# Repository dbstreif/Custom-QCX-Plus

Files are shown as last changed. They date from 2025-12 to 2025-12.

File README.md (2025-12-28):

# Custom-QCX-Plus
QRP Labs QCX+ 5W CW Radio Transceiver modified for 15m band (21MHz) frequency range. This project includes Custom Frontplate/Backplate parametric part designs, and specs/calculations for inductance and capacitance values for the transformer and low pass filter.

## Motivation
When I first began building this kit from QRP Labs, I was only a Technician Class Operator. This meant that if I wanted to get on the air and communicate globally via ionospheric propagation, I had to choose a high frequency (HF) band that I could legally transmit on. I also was restricted to only Morse Code operation on said bands, which meant that the QCX+ was the lowest barrier of entry to the world of HF and long-range communication. Now as a General Class Operator, I have more operating privileges; yet I find myself fascinated with the most pure form of radio communication, the continuous wave.

My operating band options at the time came down to 40m and 15m. The reason being, firstly, I would most likely use an end fed half wave antenna for my usual portable operation, and anything greater than a 20m antenna is quite long for all intents and purposes; and secondly, I was restricted to operating on certain bands and in-band frequency ranges. I decided that the 15m band would be best fit for me as it would give me a real design constraint, and challenge me to learn electrical principles. Also, a 15m half wave is only 7.5m, which is a small enough antenna to be portable and easily deployable.

## QCX+ Limitations
160m is not possible on the QCX+ due to crystal characteristics and 10m would introduce significant phase tuning challenges as the imaging algorithm used to display phase tuning metrics would be quite finnicky near the edges of the local oscillator range. The QCX family uses an Si5351A clock generator to create the required quadrature local oscillator (LO) signals for its direct-conversion receiver. The Si5351A can only produce two outputs with a 90deg quadrature phase difference down to about 3.2MHz. This sets the lower frequency limit for the QCX design to operate in the 80m band. The other challenge with operating at the LO edges is the phase noise introduced. When the output frequency is far from the VCO center, high divider ratios are used. At the edges, CW notes may sound unclean or raspy, weak signals might smear together, and it wouldn't be a great experience.

Here is the [datasheet](https://cdn-shop.adafruit.com/datasheets/Si5351.pdf) for the Si5351A.

## Repository Items
This repository contains a variety of different projects and calculations related to this project. Firstly, it contains inductance and capacitance values needed for proper harmonic rejection during the low pass filter stage. Secondly, it describes my thought processes and reflections of this journey, including reasoning about the [seven element Chebyshev Pi LC Low Pass Filter](https://en.wikipedia.org/wiki/Chebyshev_filter). Lastly, it includes my FreeCad parametric part designs for the Frontplate and Backplate of the custom case I built. As for the body and top, I give credit to oe7mbt for designing these. Though, because they were not designed parametrically (at least I think based on some inaccuracies), I faced problems with screw-hole alignment. You can find his creation [here](https://www.printables.com/model/65299-qrp-labs-qcx-plus-housing/files).

## Frontplate and Backplate
Here are some images of my part designs. The corner holes have countersinks so that M2.5 countersunk screws could sit flush against the plates. These plates were printed in PLA by my brother's Creality Ender-3 S1 Plus. We had just set up [Moonraker](https://moonraker.readthedocs.io/en/latest/) and [Klipper](https://github.com/Klipper3d/klipper) before printing this project, which made monitoring and adjusting print parameters really convenient.

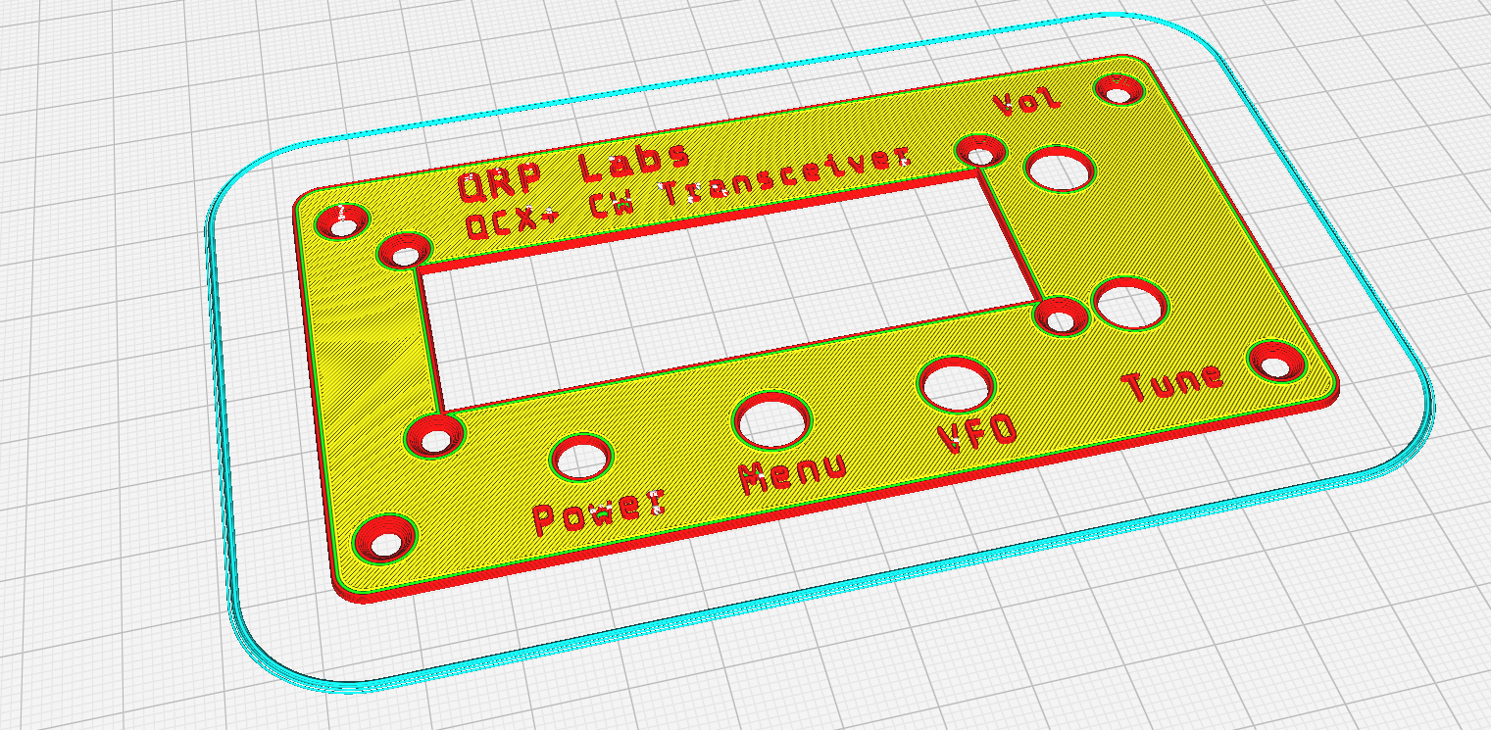
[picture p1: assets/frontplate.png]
frontplate STL Slice Frontplate Preview

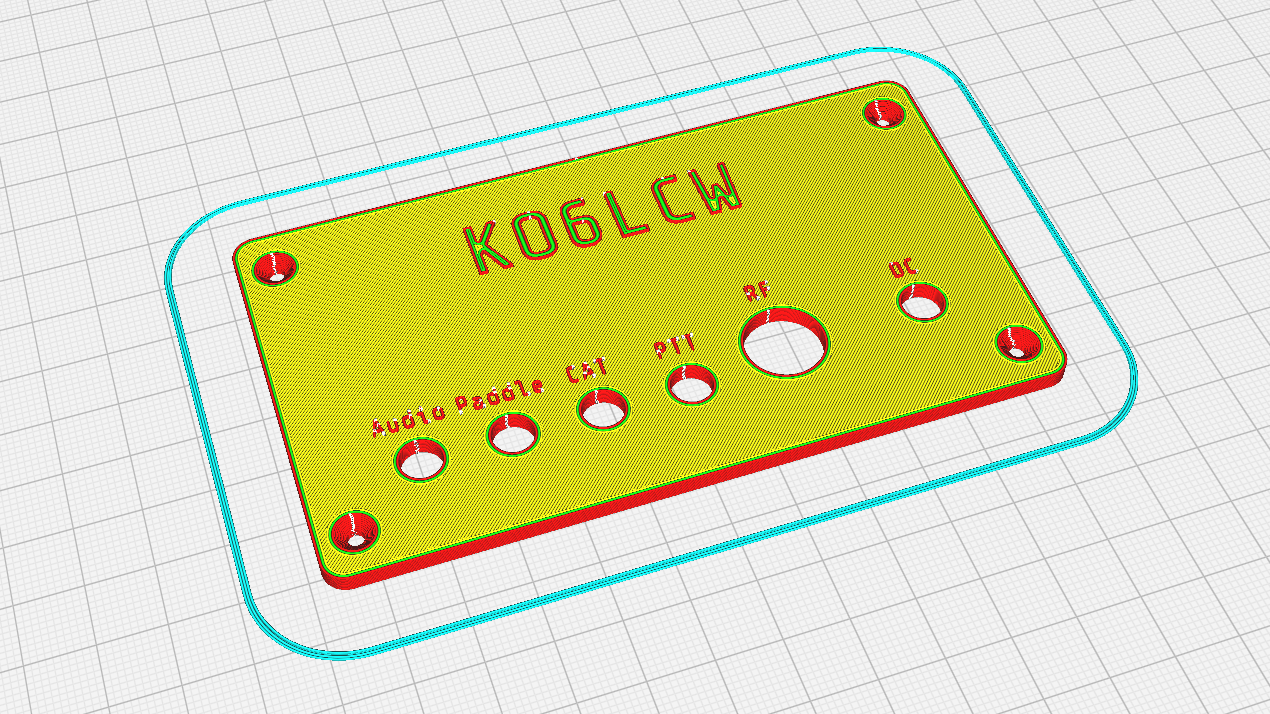
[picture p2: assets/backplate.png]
backplate STL Slice Backplate Preview

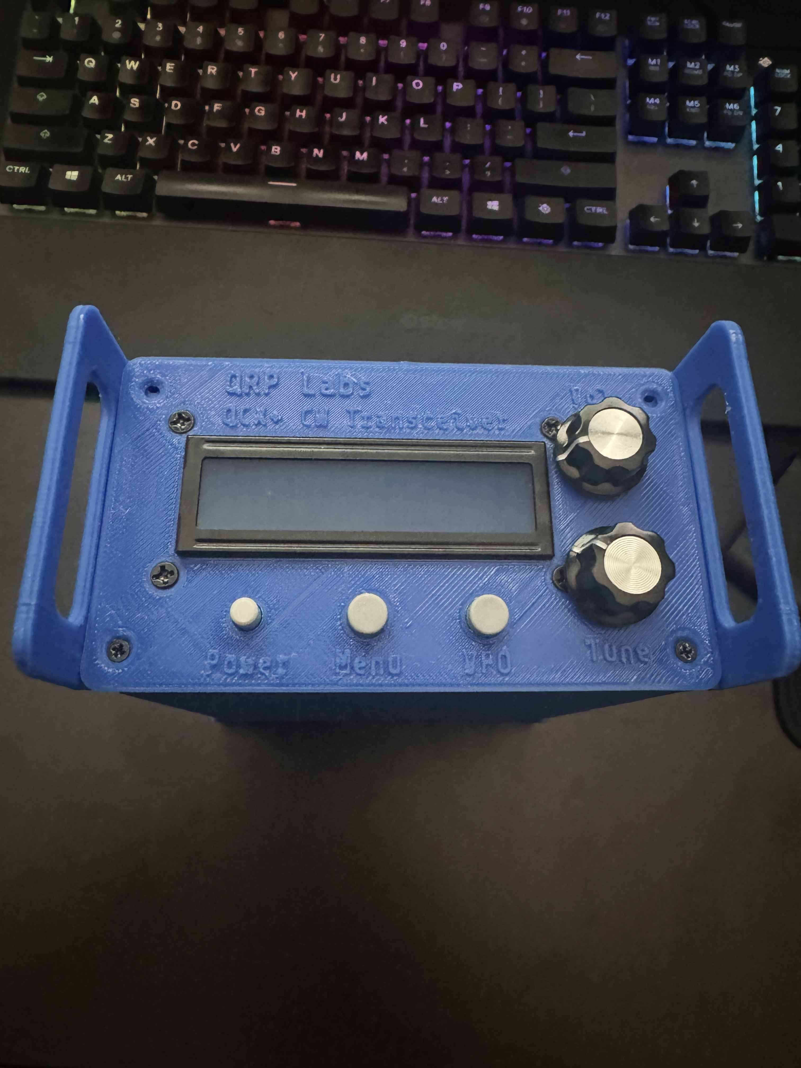
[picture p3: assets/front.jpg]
front QCX+ Front Preview

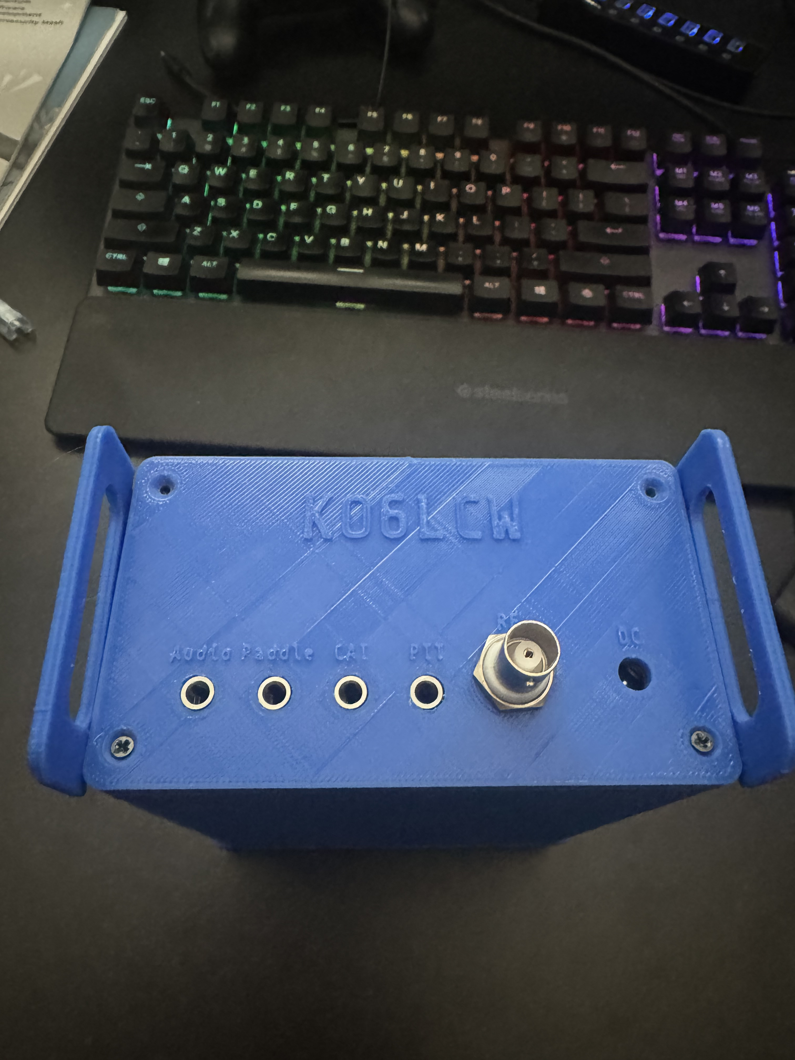
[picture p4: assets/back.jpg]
back QCX+ Back Preview

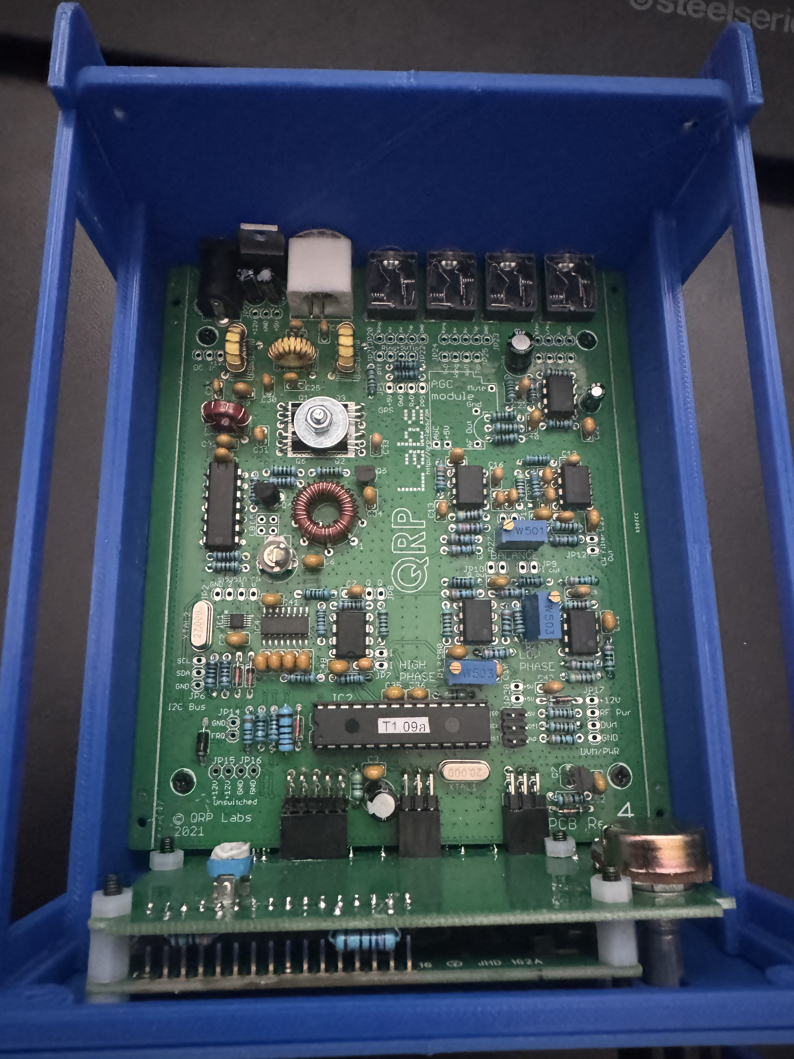
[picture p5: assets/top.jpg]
top QCX+ Top Preview

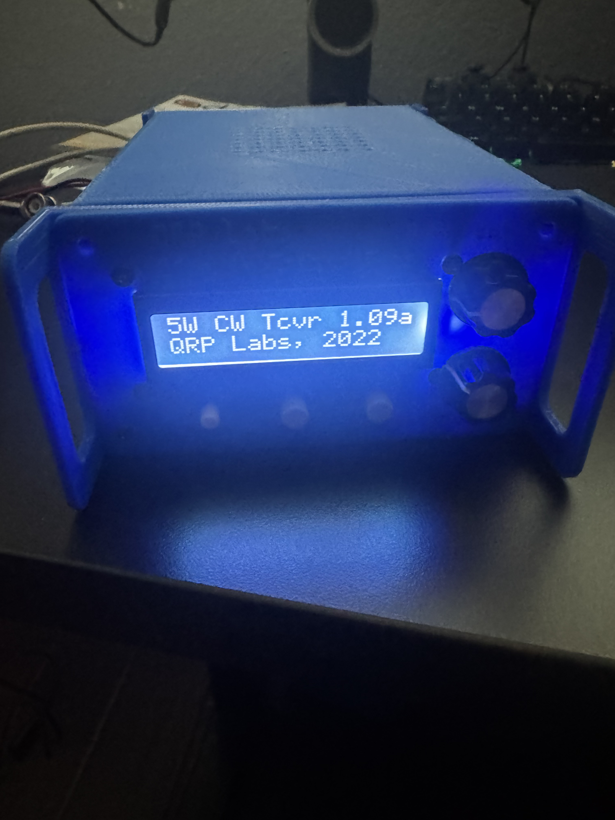
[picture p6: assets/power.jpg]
power QCX+ Powered On Preview


## Low Pass Filter Behavior
Tuning the LPF is crucial in order to maximize peak power envelope power (PEP) on transmission. On the first transmit test, the QCX+ was barely outputting 1.02W of power. After playing around with the characteristic inductance and impedance the toroidal inductors, I was able to increase output power to 3.24W with a 12V power supply. A significant increase, and close to optimal. Now the QCX+ is advertised to output around 5W PEP, however with a 12V power supply around 4W is considered maximal. If I decide to switch to a 13.8V power supply at some point, I could easily squeeze out an extra 2W. Though, I want to keep heat dissipation of the final stage power transistor low as my case is made of low polymer plastic after all.

The PEP was calculated using the Root Mean Square Voltage (RMS) PEP variant Formula: $P_{\mathrm{PEP}} = \frac{V_{\mathrm{RMS,\,peak}}^{2}}{R}$

Han's Summers uses the Omega system shortcut (8R) as we measure $V_{PP}$ using an oscope: $P_{\mathrm{PEP}} = \frac{V_{\mathrm{pp}}^{2}}{400}$

I wanted to share something interesting that I found interesting. When trying to increase inductance on L2 by "bunching up" the coil on the toroid significantly, I found that I had accidentally introduced stray capacitance and other noise. Even though output power increased to around 4.1W, the LPF was unable to correctly reject harmonic frequencies. We can observe a "double" sine wave on the oscope. 

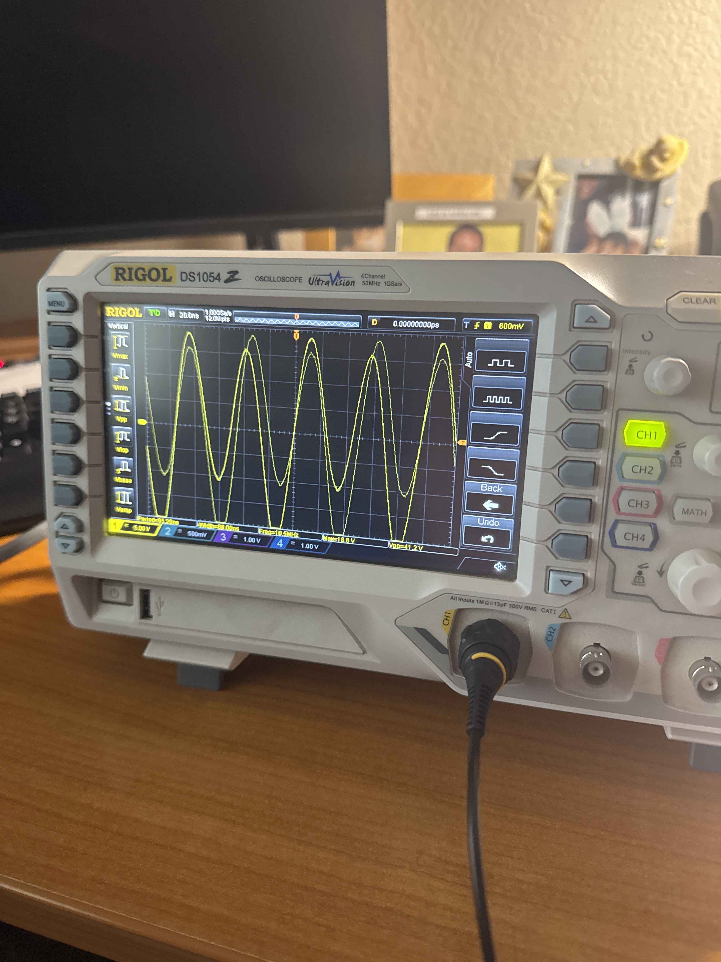
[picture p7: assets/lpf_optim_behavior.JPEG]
oscope LPF Optimization Interesting Behavior


By spacing the coil turns again, I was able to restore one clean frequency transmission or sine wave if you will. Though final tuned output power was 3.24W. I'm sure that if I were to add some turns on L2, I would have been able to squeeze more output power, however I thought that it was too much of a hassle to rewind the inductor and felt satisfied with my results.

## Conclusion
I learned a lot from this project. I have been so excited by it, that I am considering pursuing a Master's in Electrical Engineering. I find the world of RF absolutely magical and have grown a lot through this experience.

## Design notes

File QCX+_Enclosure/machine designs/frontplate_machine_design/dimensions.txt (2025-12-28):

Plate x1:
Plate: x: 116mm, y: 66mm

Radial Chamfer x4:
Radial Chamfer to Edge: r: 3.83mm

Standoff x4:
Standoff countersink outer from origin to edges: x: 3.00mm, y: 4.24mm, d: 6.00mm
Standoff hole inner from outer: d: 2.52mm, edge_dist: 1.74mm

LED Standoff x4:
Standoff countersink outer from origin to edges: x: 13.00mm, y: 20.5mm, d: 6.00mm
Standoff hole inner from outer: d: 2.52mm, edge_dist: 1.74mm

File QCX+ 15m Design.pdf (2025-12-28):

## QCX+ 15m

After receiving QRP Lab's QCX+ 5w for the 40m band, I decided that I want to operate on the 15m band instead. This is for two main reasons.

1. Antenna Length: Assuming 40m wavelength, a dipole antenna would have to be huge! 20m long or λ/2. On 15m, the typical length for each wire with 13cm tail is: 3.58m. In total it would be around 7.16m, much shorter. QE1OPW reports that at 6m height the dipole antenna performed quite well.
2. 15m band is suitable for DX no matter what time of the day, however is most useful for intercontinental communication during daylight hours, especially in years close to the solar maxima. It seems that 15m in my grid has been operating quite well in night hours. 15m band frequencies are propagated by the F2 layers of the Ionosphere.

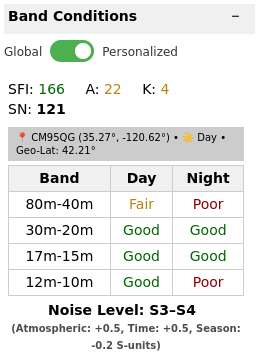
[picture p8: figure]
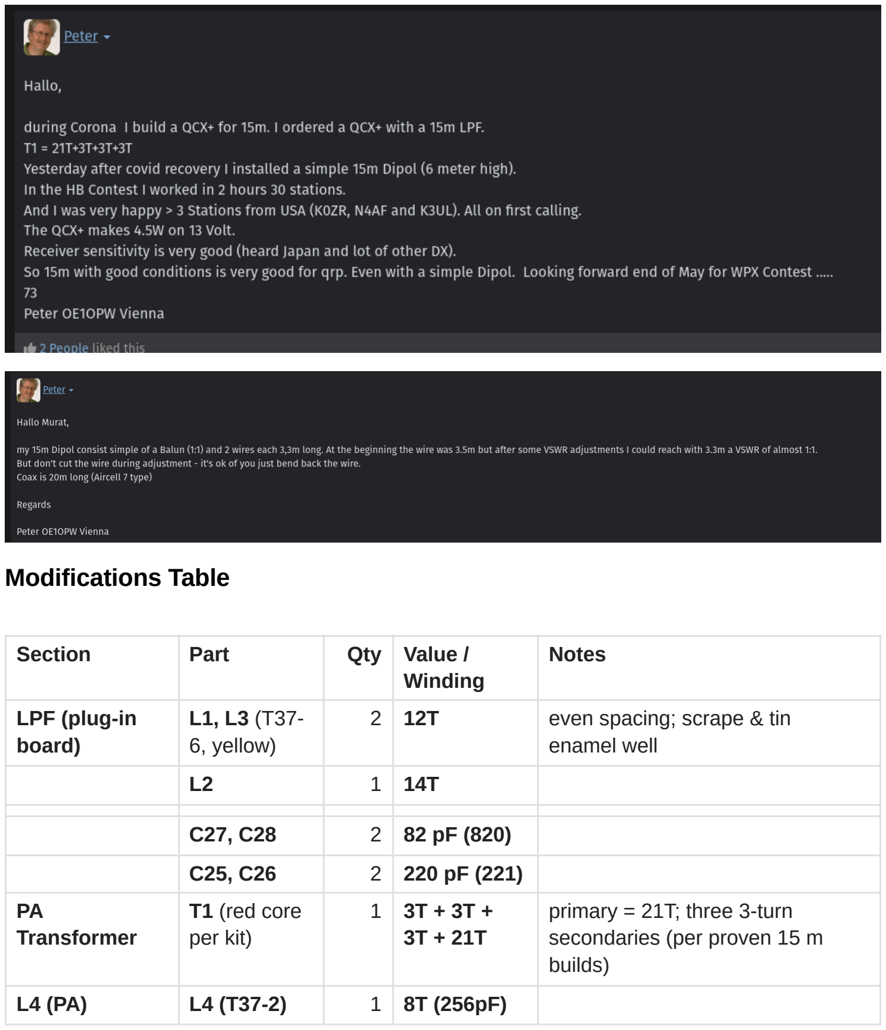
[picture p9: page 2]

### Modifications Table

Section | Part | Qty | Value / Winding | Notes
LPF (plug-in board) | L1, L3 (T37-6, yellow) | 2 | 12T | even spacing; scrape & tin enamel well
| L2 | 1 | 14T
| C27, C28 | 2 | 82 pF (820)
| C25, C26 | 2 | 220 pF (221)
PA Transformer | T1 (red core per kit) | 1 | 3T + 3T + 3T + 21T | primary = 21T; three 3-turn secondaries (per proven 15 m builds)
L4 (PA) | L4 (T37-2) | 1 | 8T (256pF)

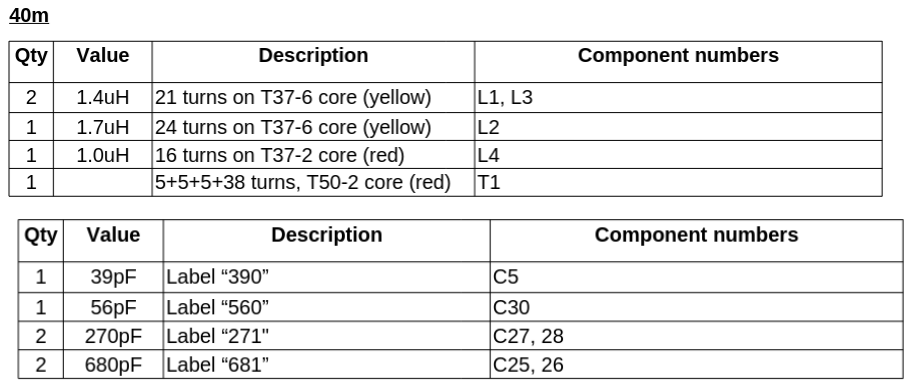
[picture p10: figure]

### Inductance Calculation for 15m LPF

QCX LPF follows a standard 7th-order Chebyshev pi-section. Each band rescales inductance and capacitance so that the cutoff frequency stays a little bit above the band's highest signal frequency:

First Let's try with 1-pole/element:

fc ∝ 1
√LC
Where,
L: Inductance
C: Capacitance

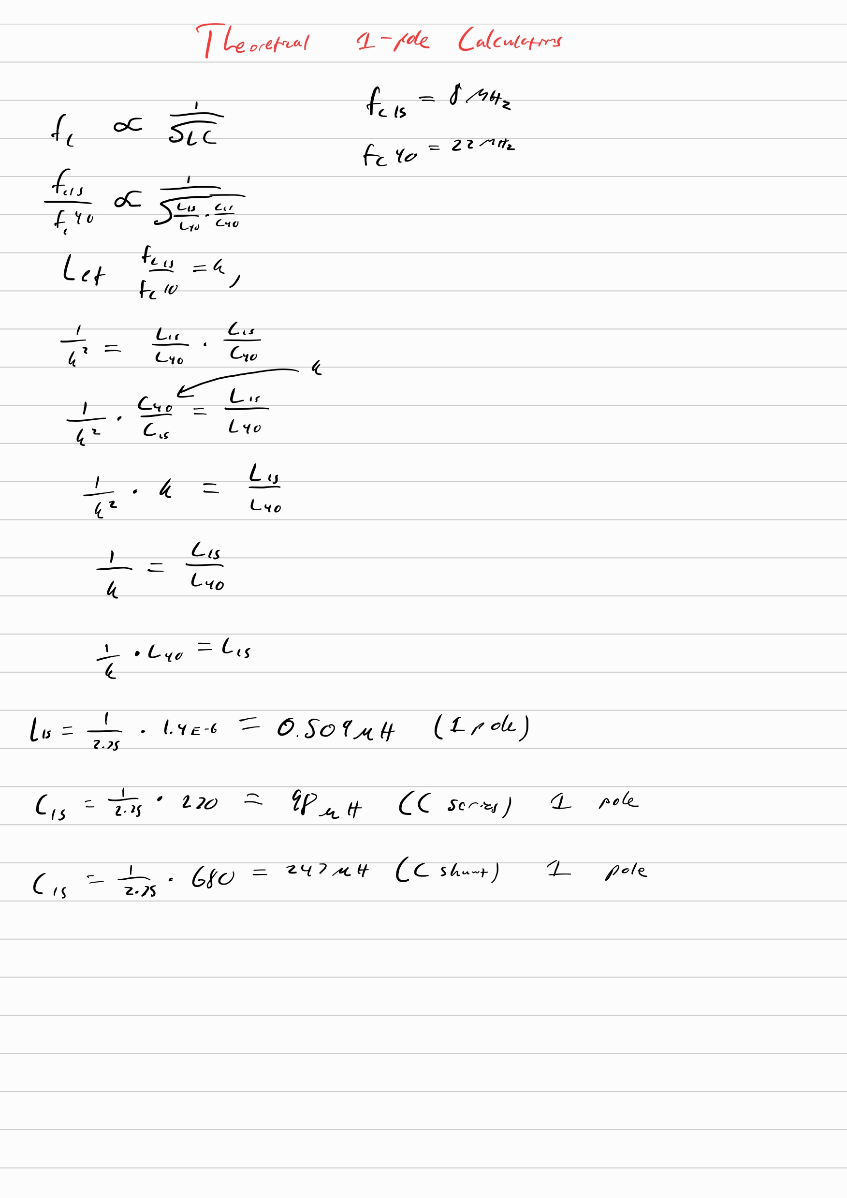
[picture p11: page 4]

Note: Capacitance was mislabeled (unit-wise) in henry. Should be micro-Farad

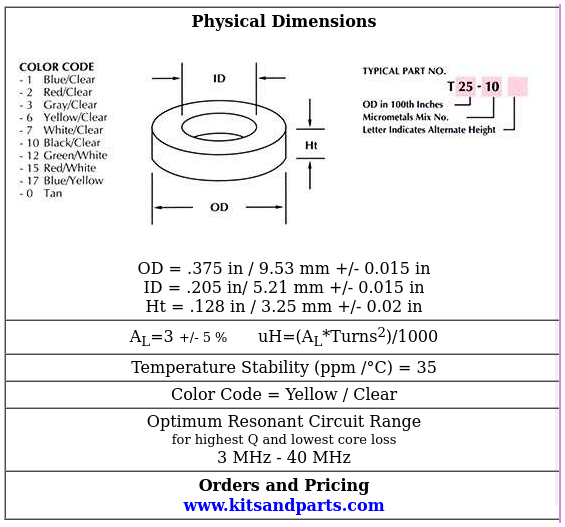
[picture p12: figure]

### W3NQN LPF Design and Values

https://qrp-labs.com/images/lpfkit/instructions2.pdf

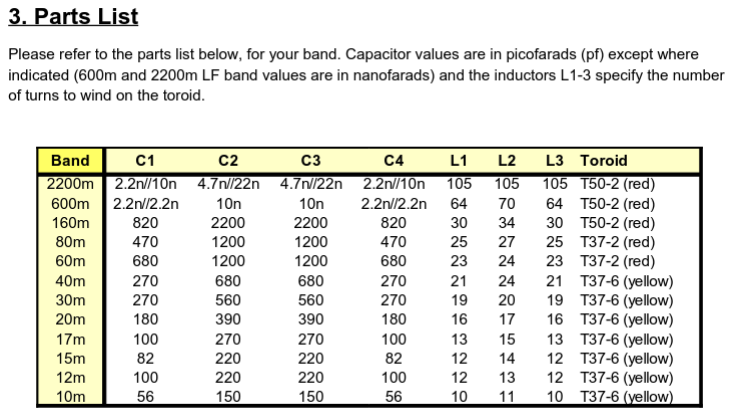
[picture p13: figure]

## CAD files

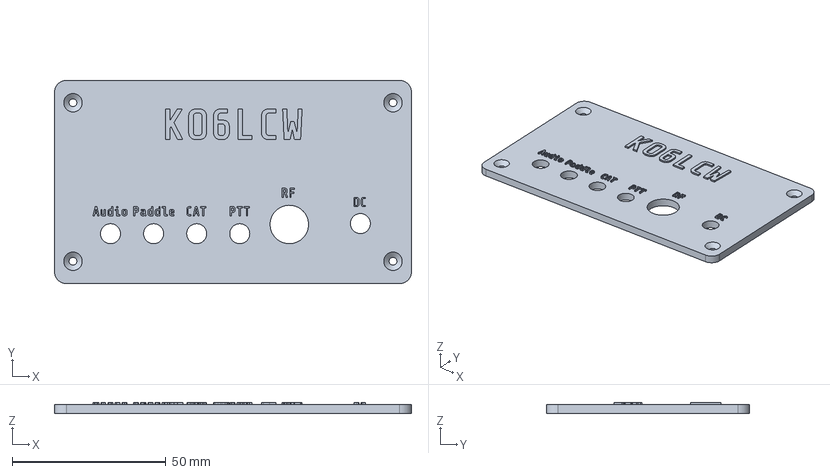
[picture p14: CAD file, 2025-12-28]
QCX+_Enclosure/machine designs/backplate_machine_design/backplate.FCStd
116.0 x 66.0 x 3.60 mm

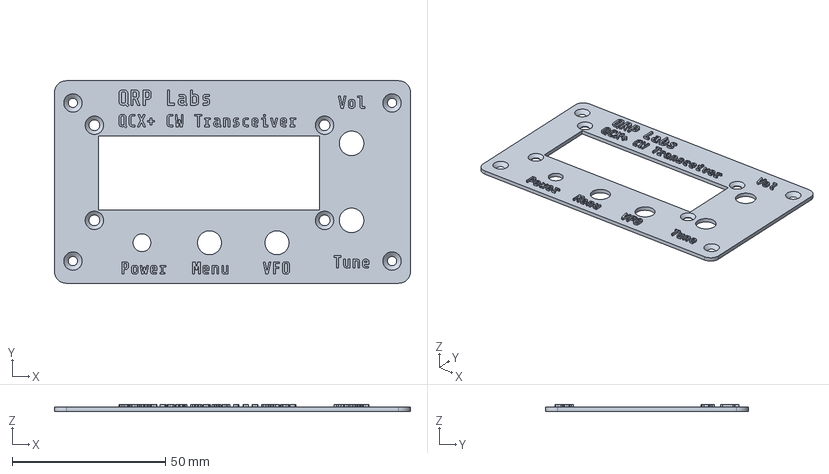
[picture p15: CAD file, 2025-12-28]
QCX+_Enclosure/machine designs/frontplate_machine_design/frontplate.FCStd
116.0 x 66.0 x 2.30 mm

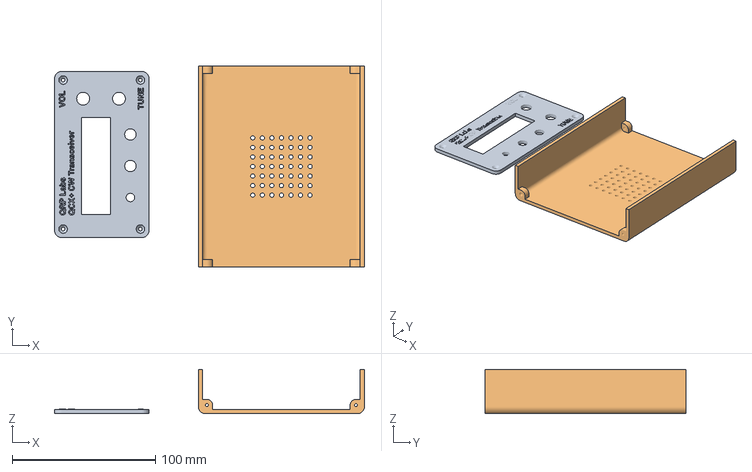
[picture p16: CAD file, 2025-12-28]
QCX+_Enclosure/QCX+ Printing Design/Printer Files/CE3S1P_QCX+-QCX+ Housing_Front&speaker.3mf
216.4 x 140.0 x 31.0 mm
QCX+-QCX+ Housing_Front.stl
QCX+-QCX+ Top_Speaker.stl

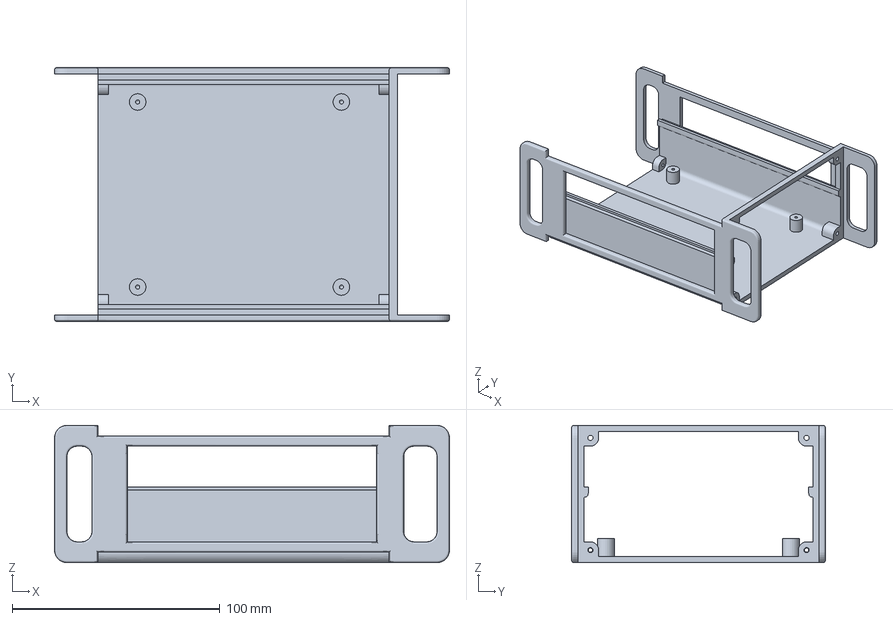
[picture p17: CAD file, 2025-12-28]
QCX+_Enclosure/QCX+ Printing Design/Printer Files/CE3S1P_QCX+-QCX+ Housing_Base_w_Protector.3mf
190.0 x 122.0 x 66.0 mm

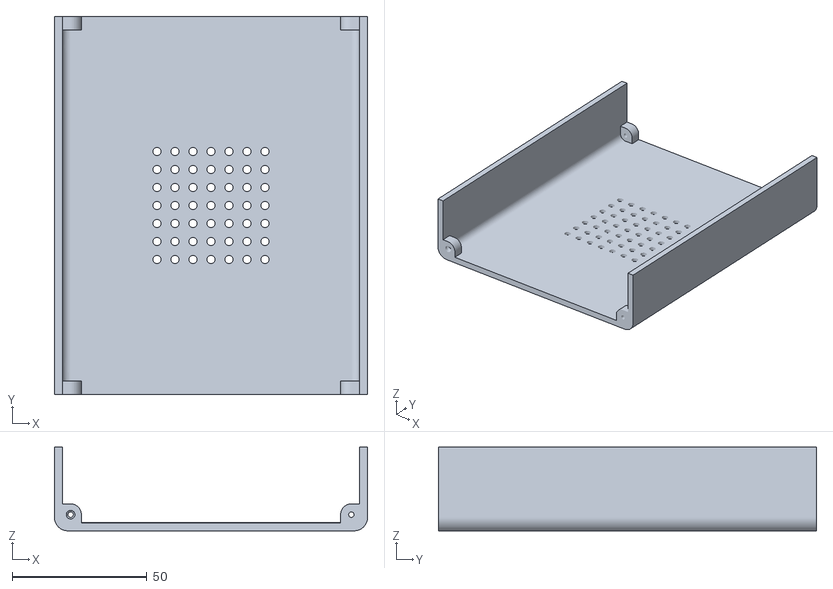
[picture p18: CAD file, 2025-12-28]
QCX+_Enclosure/QCX+ Printing Design/STL Files/QCX+-QCX+ Top_Speaker.stl
116.0 x 140.0 x 31.0

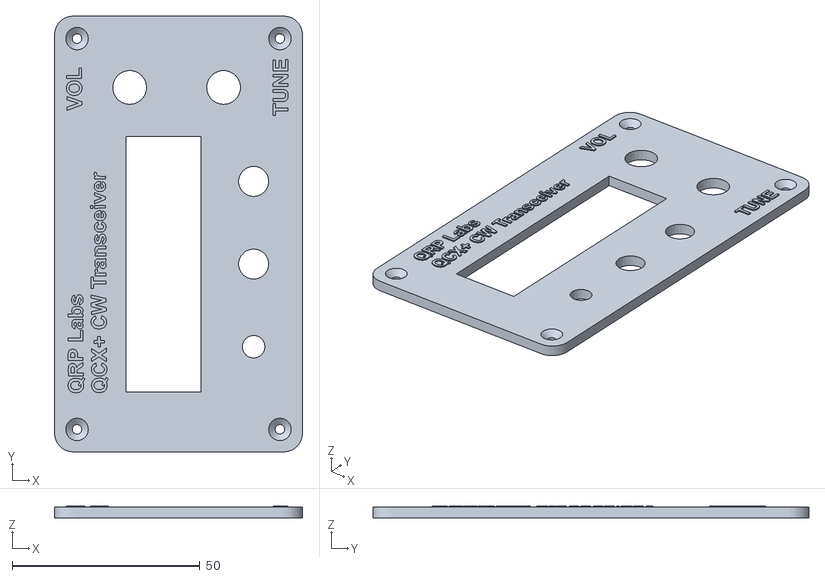
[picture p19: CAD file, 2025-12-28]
QCX+_Enclosure/QCX+ Printing Design/STL Files/QCX+-QCX+ Housing_Front.stl
66.0 x 116.0 x 3.30

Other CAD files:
QCX+_Enclosure/QCX+ Printing Design/STL Files/backplate.stl
QCX+_Enclosure/QCX+ Printing Design/STL Files/QCX+-QCX+ Housing_Base_w_Protector.stl
QCX+_Enclosure/QCX+ Printing Design/STL Files/frontplate.stl
QCX+_Enclosure/QCX+ Printing Design/QCX+.blend
